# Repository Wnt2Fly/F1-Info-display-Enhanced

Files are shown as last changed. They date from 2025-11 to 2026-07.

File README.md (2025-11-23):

# F1 Tracker - 3 Color E-Paper Display with Enhanced Features

This is an enhanced version of https://github.com/mazur888/F1-Info-display. Including new features, caching and adjustable updates. Designed specifically for a ESP32-C3 Supermini and a 3-color e-paper display. Shows race calendar, driver standings, constructor standings, starting grids, and race results with intelligent update scheduling based on race timing.

<p align="center">
<a href="https://www.buymeacoffee.com/wnt2fly" target="_blank">Buy Me A Coffee</a>
</p>

  

## Features

- 📅 **Race Calendar** - Shows next and last race information
- 🏁 **Starting Grid** - Displays qualifying positions when available (within 18h of race)
- 🏆 **Driver Standings** - Top 10 drivers with points
- 🏎️ **Constructor Standings** - Top 5 constructors with points
- 🥇 **Race Results** - Podium finishers from last race
- ⏱️ **Countdown Timer** - Time until next race with local timezone support
- 🔄 **Smart Updates** - Update frequency adapts based on proximity to race events
- 💾 **Intelligent Caching** - Reduces API calls with multi-level caching
- 🌐 **WiFi Manager** - Easy WiFi setup via captive portal

## Hardware Requirements

### Required Components
- **ESP32-C3 Mini** (or compatible ESP32-C3 board)
- **3-Color E-Paper Display** - GxEPD2_290_C90c (296x128 pixels)
- **SPI Connections** - For display communication
- **Power Supply** - 3.3V/5V depending on your setup

### Pin Connections

| Display Pin | ESP32-C3 Pin | Function |
|---|---|---|
| BUSY | GPIO 4 | Busy signal |
| RST | GPIO 5 | Reset |
| DC | GPIO 7 | Data/Command |
| CS | GPIO 3 | Chip Select |
| SCK | GPIO 6 | SPI Clock |
| MOSI | GPIO 10 | SPI Data |

## Installation

### 1. Arduino IDE Setup

1. Install **Arduino IDE** (1.8.x or 2.x)
2. Add ESP32 board support:
   - File → Preferences → Additional Boards Manager URLs
   - Add: `https://raw.githubusercontent.com/espressif/arduino-esp32/gh-pages/package_esp32_index.json`
   - Tools → Board → Boards Manager → Search "ESP32" → Install

### 2. Install Required Libraries

Install the following libraries via Library Manager (Sketch → Include Library → Manage Libraries):

- **ArduinoJson** (v7.x) - JSON parsing
- **GxEPD2** - E-paper display driver
- **U8g2_for_Adafruit_GFX** - Font rendering
- **WiFiManager** - WiFi configuration
- **Preferences** - Built-in ESP32 library

### 3. Board Configuration

**Tools → Board:** Select your ESP32-C3 board (e.g., "ESP32C3 Dev Module")

**Tools → Partition Scheme:** Select **"Huge APP (3MB No OTA)"** or **"No OTA (3MB)"**
- This gives you 3MB for your application (vs 1.4MB with OTA partition)

**Other Settings:**
- **Flash Size:** 4MB (if available)
- **CPU Frequency:** 160MHz (or 80MHz for lower power)
- **Upload Speed:** 921600 (or lower if you have issues)

### 4. Upload Code

1. Open `F1_Tracker_3Color.ino` in Arduino IDE
2. Connect ESP32-C3 via USB
3. Select correct COM port (Tools → Port)
4. Click Upload

## First Time Setup

### WiFi Configuration

On first boot, the device will create a WiFi access point:

1. **SSID:** `F1Tracker-Setup`
2. **Password:** `formula1`
3. Connect to this network from your phone/computer
4. A captive portal should open automatically (or navigate to `192.168.4.1`)
5. Select your home WiFi network and enter password
6. The device will save credentials and connect

The display will show setup instructions during this process.

### Display Modes

The display automatically switches between 4 modes based on race timing:

**Mode 1: Normal Operation** (>18 hours before race):
- Shows driver standings (top 10)
- Shows constructor standings (top 5)
- Shows last race podium (if results available)
- Shows next race countdown

**Mode 2: Race Approaching** (within 18h before race, grid available):
- Switches to starting grid (qualifying positions)
- Shows constructor standings (top 5)
- Hides old podium, shows "Awaiting Results"
- Shows next race info with "Awaiting Results" message

**Mode 3: Race In Progress** (race started, results not available yet):
- Shows "Current Race: [Name]"
- Shows "Race in Progress!"
- Shows starting grid (continues during race)
- Shows empty podium (no names, just boxes)

**Mode 4: Post-Race** (results available):
- Shows driver standings (switched from grid)
- Shows constructor standings (top 5)
- Shows last race podium with winner names
- Shows next race information

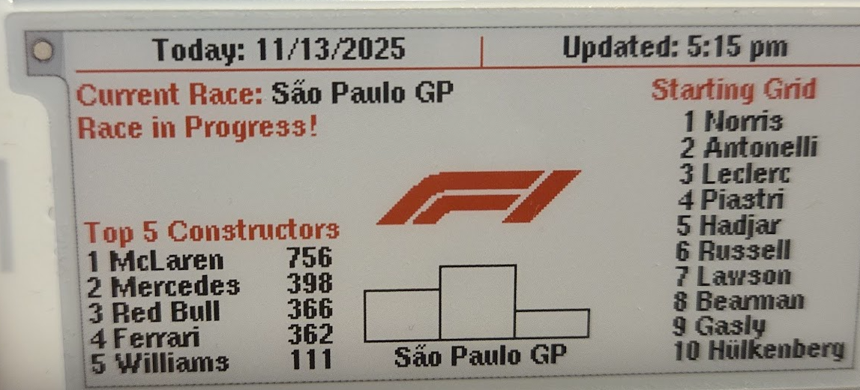
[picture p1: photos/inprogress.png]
Race in Progress Screen


## Update Schedule

The display automatically adjusts update frequency based on race timing:

| Time Before Race | Update Frequency | Reason |
|---|---|---|
| **>48 hours** | Every 6 hours | Nothing changes, minimal updates |
| **24-48 hours** | Every 2 hours | Grid might be posted |
| **<24 hours** | Every 30 minutes | Actively searching for starting grid |
| **Grid Found** | Every 2 hours | Grid found, back to normal until race |
| **Race Window** (6h before to 6h after) | Every 30 minutes | Frequent updates during race event |
| **After Race** | Every 2 hours | Normal operation |

**Update Times:**
- 6-hour updates: 12:00 AM, 6:00 AM, 12:00 PM, 6:00 PM
- 2-hour updates: Even hours at :00 (12:00 AM, 2:00 AM, 4:00 AM, etc.)
- 30-minute updates: :00 and :30 of every hour

## API Information

### Data Source
- **API:** Ergast F1 API (via jolpi.ca proxy)
- **Base URL:** `https://api.jolpi.ca/ergast/f1/{year}/`
- **Endpoints Used:**
  - `/races.json` - Race calendar
  - `/driverstandings.json` - Driver championship
  - `/constructorstandings.json` - Constructor championship
  - `/{round}/qualifying.json` - Starting grid
  - `/{round}/results.json` - Race results

### Caching Strategy

The code uses intelligent multi-level caching:

- **Calendar Cache:** 1 hour TTL
- **Standings Cache:** 1 hour TTL (invalidated when race finishes)
- **Qualifying Cache:** 24 hours TTL (never changes once posted)
- **Results Cache:** 1 hour TTL
- **Availability Cache:** 
  - Qualifying: 12 hours (never changes once posted)
  - Results: 5 minutes (can appear after race)

This reduces API calls by ~99% compared to no caching.

## Configuration

### Timezone

Default timezone is set to **EST/EDT** (Eastern Time). To change:

Edit line 147 in `F1_Tracker_3Color.ino`:
```cpp
#define MY_TZ "EST5EDT,M3.2.0/2,M11.1.0/2"
```

For other timezones, use TZ format:
- PST: `"PST8PDT,M3.2.0/2,M11.1.0/2"`
- GMT: `"GMT0"`
- See [TZ database](https://en.wikipedia.org/wiki/List_of_tz_database_time_zones) for full list

### Update Intervals

Update frequencies can be adjusted in the code (lines 32-35):

```cpp
const int UPDATE_INTERVAL_FAR_MIN = 360;        // >48h: 6 hours
const int UPDATE_INTERVAL_NORMAL_MIN = 120;     // Normal: 2 hours
const int UPDATE_INTERVAL_RACE_WINDOW_MIN = 30; // Race window: 30 min
const int UPDATE_INTERVAL_GRID_SEARCH_MIN = 30; // Grid search: 30 min
```

### Debug Mode

Debug mode allows you to test all display modes without waiting for actual race events. It simulates different times relative to a past race, allowing you to cycle through all scenarios interactively.

#### Enabling Debug Mode

1. Open `F1-Info-display-Enhanced.ino` in Arduino IDE
2. Find line 42: `#define DEBUG_MODE 0`
3. Change to: `#define DEBUG_MODE 1`
4. Upload the code

#### Using Debug Mode

1. **Open Serial Monitor** (115200 baud)
2. **Wait for initial setup** - Let the device connect to WiFi and fetch calendar data
3. **Use interactive commands** to test different scenarios

#### Interactive Menu

When debug mode starts, an interactive menu is displayed. You can use either **numbers (1-8)** or **full commands**:

**Menu Options:**
- `1` or `normal` - Jump to 3 days before race (Mode 1: Normal Operation)
- `2` or `before` - Jump to 2 hours before race (Mode 2: Race Approaching)
- `3` or `during` - Jump to race start time (Mode 3: Race In Progress)
- `4` or `after` - Jump to 5 hours after race start (Mode 4: Post-Race)
- `5` or `refresh` - Force immediate display update
- `6` or `status` - Show current offset, real time, simulated time, and race state
- `7` or `reset` - Reset to default offset (-30 days)
- `8` or `autorefresh` - Toggle auto-refresh on/off (default: OFF in debug mode)

**Time Adjustments** (also available):
- `+1h`, `+2h`, `+6h` - Add hours to time offset
- `-1h`, `-2h`, `-6h` - Subtract hours from time offset
- `+1d`, `+2d`, `+7d` - Add days to time offset
- `-1d`, `-2d`, `-7d` - Subtract days from time offset
- `set <seconds>` - Set exact time offset (e.g., `set -2592000`)

**Menu Commands:**
- `menu` or `help` or `?` - Show menu again

#### Example Workflow

```
1. Upload code with DEBUG_MODE = 1
2. Open Serial Monitor (115200 baud)
3. Wait for calendar fetch
4. Type "status" - see current state
5. Type "normal" - see Mode 1 (driver standings, countdown)
6. Type "before" - see Mode 2 (starting grid, awaiting results)
7. Type "during" - see Mode 3 (race in progress, empty podium)
8. Type "after" - see Mode 4 (post-race, results if available)
```

#### Important Notes

- **Commands are case-insensitive** (e.g., `STATUS` = `status`)
- **Serial Monitor settings:** 115200 baud, "Newline" or "Both NL & CR" line ending
- **Display refresh takes 15-30 seconds** - this is normal for e-paper displays
- **Menu reappears after commands** - After each mode command (1-4) or refresh (5) completes, the menu is shown again
- **Auto-refresh disabled by default** - Display only updates when you select a menu option (1-5)
- **WiFi stays connected** - In debug mode, WiFi remains connected for faster testing
- **Jump commands auto-refresh** - Options 1-4 automatically update the display after jumping to that time
- **Time adjustments don't refresh** - Use `+1h`, `-2h`, etc. then type `5` or `refresh` to update display
- **API calls use real time** - Debug mode only affects time calculations, not API data

#### Debug Mode Display Indicator

When debug mode is enabled, the display shows `[DEBUG] Mode X` in the header (where X is 1-4) instead of `Today:` to indicate you're in test mode and show the current display mode.

## Power Consumption

- **During Update:** ~50-100mA (display refresh takes ~15-30 seconds)
- **Hibernating:** ~10-20µA (display in deep sleep)
- **Average:** Very low due to hibernation between updates
- **Battery Life:** Weeks to months depending on update frequency and battery capacity

## Troubleshooting

### Display Not Updating

1. **Check WiFi Connection**
   - Serial monitor will show connection status
   - Device restarts if WiFi disconnects

2. **Check Time Sync**
   - Device needs NTP time sync to work
   - Serial monitor shows time sync status
   - Ensure internet connection is working

3. **Check API Access**
   - Serial monitor shows API call status
   - Verify API endpoint is accessible

### Display Shows Garbage/Corruption

1. **Power Supply**
   - Ensure stable 3.3V/5V power
   - Display needs adequate current during refresh

2. **SPI Connections**
   - Verify all pins connected correctly
   - Check for loose connections

3. **Full Refresh**
   - Display uses full refresh (not partial)
   - This is normal for 3-color displays

### WiFi Setup Issues

1. **Can't Connect to Setup AP**
   - SSID: `F1Tracker-Setup`
   - Password: `formula1`
   - Some devices may not auto-open portal - navigate to `192.168.4.1`

2. **WiFi Credentials Not Saving**
   - Check Preferences library is working
   - Device should remember credentials after first setup

### Compilation Errors

1. **"Board not found"**
   - Install ESP32 board support (see Installation)

2. **"Library not found"**
   - Install required libraries (see Installation)

3. **"Partition too small"**
   - Select "Huge APP (3MB No OTA)" partition scheme

## Technical Details

### Memory Usage

- **Flash:** ~450KB (code + libraries)
- **RAM:** ~40-70KB (with 400KB available on ESP32-C3)
- **JSON Buffer:** 12KB (optimized from 16KB)

### Display Specifications

- **Model:** GxEPD2_290_C90c
- **Resolution:** 296x128 pixels
- **Colors:** Black, White, Red (3-color)
- **Refresh Time:** ~15-30 seconds (full refresh)
- **Rotation:** 270° (landscape mode)

### Code Structure

- **Main Loop:** Checks time every 60 seconds, triggers updates on schedule
- **Update Function:** Fetches data, draws to display, hibernates
- **Caching:** Multi-level cache reduces API calls
- **Error Handling:** Graceful degradation on API failures
- **Debug Mode:** Interactive time simulation for testing all display modes

## License

This project is open source. Feel free to modify and use as needed.

## Credits

- **F1 Data:** Ergast F1 API (via jolpi.ca)
- **Display Library:** GxEPD2 by ZinggJM
- **Font Rendering:** U8g2
- **WiFi Management:** WiFiManager by tzapu

## Support

For issues or questions:
1. Check Serial Monitor output for debug information
2. Verify all connections and power supply
3. Ensure WiFi and internet connectivity
4. Check API endpoint accessibility

---

**Enjoy your F1 Tracker! 🏎️🏁**

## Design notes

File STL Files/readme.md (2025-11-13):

##  Like this project? [Buy me a coffee](coff.ee/mazur888)  

## Printer:  
I used Creality K1C  
hyper pla, no supports default speed and layer settings in creality print.  

## What else is needed:  
#1 One or two small screws to attach front frame to base (there are 2 pilot holes).  
#2 One USB C connector like this (2 or 4 wire):  
#3 Optional: 2x 5k1 resistors.  

## Electronics:  
#1  If you dont care about USB C to C you can use **2 wire connector** and solder positive to esp32 dev board's 5V and GND to GND,  
this will give you standard USB A to USB C option only, C to C wont work.

#2 If you want to use C- C cable, you have to buy **4 wire connector**. Solder positive to esp32 dev board's 5V, GND to GND,  
and solder resistors between CC1 and GND, and CC2 and GND to enable power when used C to C cables. 

## Assembly:  
#1 place screen in to front frame and using soldering iron melt corner pins to hold screen in place,  
#2 fish usb connector cable from bottom compartment through back plate into screen and solder wires,  
#3 close back cover and place front in base,  
4# secure front using small screw through bottom compartment,  
5# use bottom compartment to hide excess cable and close it using bottom cap.    

## Connector type used:  
Screenshot From 2025-07-17 09-56-34

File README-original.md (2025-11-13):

# Formula 1 Info tracker  
  
main1 

## Pole Position before race:  

pole

## Dashboard     
  
Dash 1
   
## About this project  
Formula 1 info screen, is based on esp32 and **2.9"  3 color E-Paper module from weact studio** and ergast API, It allows to track Formula 1 events, dates, points, stats and many more on e-paper display and weserver dashboard.  
  
**Features:**  
  
- mDNS option (**f1tracker.local**), or device IP address for dashboard or OTA  
- Data is fetched from **ergast** API and displayed on the screen every 30 minutes,  
- OTA Uploads  
- Full online dashboard including season calendar, all season rounds, pole positions, driver points etc..  
- Automatic winter/summer time change  
- wifi AP mode for fast wifi setup  
    
**Default data on E-paper:**  
  
- Top 5 Teams including constructors points for current season   
- Top 10 drivers including season points   
- Last race location including podium places   
- Next race location and date  
- Pole position for next race  
  
<p align="center">
<a href="https://www.buymeacoffee.com/mazur888" target="_blank">Buy Me A Coffee</a>
</p>
  
## **Hardware:**  
E-Paper module: [2.9 Inch 3-color weact studio e-paper module](https://www.aliexpress.com/item/1005005183232092.html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)  
ESP32: [Esp32 dev board](https://www.aliexpress.com/item/1005005476182210.html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)
  
**ESP32 to Screeen Connections:**  
BUSY = 4  
CS = 5  
RST = 16  
DC = 17  
SCK = 18  
MISO = 19  
MOSI = 23  
  
## **Software:**
**WiFI access point login details:**  
- SSID "F1 display"  
- PASS "formula1"  
  
**Time zones:**  
- Change time zone to match your location. default time zone is BST for United Kingdom  
  
MET-1METDST,M3.5.0/01,M10.5.0/02   //Europe  
CET-1CEST,M3.5.0,M10.5.0/3         // Central Europe  
EST-2METDST,M3.5.0/01,M10.5.0/02   // Europe  
EST5EDT,M3.2.0,M11.1.0           // EST USA  
CST6CDT,M3.2.0,M11.1.0           // CST USA  
MST7MDT,M4.1.0,M10.5.0           // MST USA  
NZST-12NZDT,M9.5.0,M4.1.0/3      // Auckland  
EET-2EEST,M3.5.5/0,M10.5.5/0     // Asia  
ACST-9:30ACDT,M10.1.0,M4.1.0/3   // Australia  
  
**API Updates:**  
- Screen and dashboard updates are pulled from server every 30 minutes
  
**Software Updates:**  
- If you wish to update the software, OTA server is available under devices IP or f1tracker.local
  
## **Third‑Party Libraries**  
- **GxEPD2** (v1.6.4) by ZinggJM — GPL 3.0  
- **U8g2_for_Adafruit_GFX** (v1.8.0) by olikraus — BSD 2‑Clause  
- **WiFiManager** (v2.0.17) by tzapu — MIT  
- **ArduinoJson** (v7.4.2) by Benoit Blanchon — MIT

## Enclosure
- STL Files are included in this project  
  
**Printer:**  
Any printer will be ok, For this project I used Creality K1C and hyper pla  
all settings default in creality print  
printed with no supports  
  
## License
This project is released under the [GNU GPL v3.0](LICENSE).  
© 2025 Mazur888. No warranty; use at your own risk.

<p align="center">
<a href="https://www.buymeacoffee.com/mazur888" target="_blank">Buy Me A Coffee</a>
</p>

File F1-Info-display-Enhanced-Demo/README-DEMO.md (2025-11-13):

# F1 Tracker - Demo Mode

A demonstration version of the F1 Tracker that automatically cycles through all display modes. This is designed for **taking photos** of the device in different states and is **NOT intended for production use**.

## ⚠️ Important Notice

**This is a TEMPORARY demo file to verify your setup is working**

- **DO NOT** use this in production
- **DO NOT** leave this running permanently
- Use `F1-Info-display-Enhanced.ino` for normal operation

## Purpose

This demo file automatically cycles through all 4 display modes every 7 seconds, making it easy to photograph the device showing:
- Normal operation mode
- Race approaching mode
- Race in progress mode
- Post-race mode

## Features

### Automatic Mode Cycling
- **4 Display Modes** that cycle automatically
- **7-second intervals** between mode changes (configurable)
- **Real API data** from Ergast F1 API
- **Continuous loop** until power off or code change

### Display Modes

#### Mode 0: Normal Operation
- **Top 10 Drivers** standings with points
- **Top 5 Constructors** standings
- **Last Race Podium** with winner names
- **Next Race** information with countdown

#### Mode 1: Race Approaching (Within 18h)
- **Starting Grid** (qualifying positions)
- **Top 5 Constructors** standings
- **"Awaiting Results"** podium placeholder
- **Next Race** information

#### Mode 2: Race In Progress
- **"Race in Progress!"** indicator
- **Starting Grid** (current race)
- **Top 5 Constructors** standings
- **Empty Podium** (no results yet)

#### Mode 3: Post-Race
- **Top 10 Drivers** standings with points
- **Top 5 Constructors** standings
- **Last Race Podium** with winner names
- **Next Race** information

## Hardware Requirements

Same as the main F1 Tracker:
- **ESP32-C3 Mini** (or compatible ESP32-C3 board)
- **3-Color E-Paper Display** - GxEPD2_290_C90c (296x128 pixels)
- **SPI Connections** - See pin mapping below

### Pin Connections

| Display Pin | ESP32-C3 Pin | Function |
|---|---|---|
| BUSY | GPIO 4 | Busy signal |
| RST | GPIO 5 | Reset |
| DC | GPIO 7 | Data/Command |
| CS | GPIO 3 | Chip Select |
| SCK | GPIO 6 | SPI Clock |
| MOSI | GPIO 10 | SPI Data |

## Installation

### 1. Prerequisites

Same requirements as the main project:
- **Arduino IDE** (1.8.x or 2.x)
- **ESP32 board support** installed
- **Required libraries:**
  - ArduinoJson (v7.x)
  - GxEPD2
  - U8g2_for_Adafruit_GFX
  - WiFiManager

### 2. Upload Demo Code

1. Open `F1-Info-display-Enhanced-Demo.ino` in Arduino IDE
2. Select your ESP32-C3 board
3. Select partition scheme: **"Huge APP (3MB No OTA)"**
4. Connect ESP32-C3 via USB
5. Select correct COM port
6. Click **Upload**

### 3. First Run

On first boot:
1. Device creates WiFi AP: `F1Tracker-Setup` (password: `formula1`)
2. Connect to this network from your phone/computer
3. Select your home WiFi network in the captive portal
4. Device connects and fetches F1 data
5. Demo mode starts automatically

## Usage

### Starting the Demo

1. **Upload the code** to your ESP32-C3
2. **Wait for WiFi connection** (first time setup may be needed)
3. **Data loads** - you'll see "DEMO MODE - Cycling through all modes..."
4. **Demo starts** - modes cycle automatically every 7 seconds

### Taking Photos

1. **Position your camera** ready to photograph the display
2. **Wait for the mode** you want to capture
3. **Take the photo** - you have 7 seconds per mode
4. **Wait for next mode** or restart if needed

### Mode Timing

- Each mode displays for **7 seconds**
- Full cycle (4 modes) takes **28 seconds**
- Modes cycle in order: 0 → 1 → 2 → 3 → 0 (repeat)

### Stopping the Demo

- **Power off** the device, or
- **Upload different code** (e.g., the main F1 Tracker code)

## Configuration

### Changing Display Interval

To change how long each mode displays, edit line 26 in the demo file:

```cpp
const int DEMO_DELAY_MS = 7000;  // Change this value (in milliseconds)
```

Examples:
- `5000` = 5 seconds per mode
- `10000` = 10 seconds per mode
- `15000` = 15 seconds per mode

### Changing Starting Mode

To start from a different mode, edit line 25:

```cpp
int demoMode = 0;  // 0=Normal, 1=Race Approaching, 2=Race In Progress, 3=Post-Race
```

## Serial Monitor Output

The demo provides detailed serial output:

```
=== F1 TRACKER DEMO MODE ===
Cycles through all display modes every 7 seconds

[WiFi] Starting WiFi setup...
[WiFi] Connected!
IP: 192.168.1.xxx

[Time] Synced!

[DEMO] Fetching calendar data...
[DATA] Last: R23 Abu Dhabi GP
[DATA] Next: R1 Bahrain GP

[DEMO] Data loaded. Starting mode cycle...

[DEMO] Switching to mode 0
[DEMO] Mode 0: Normal
[DEMO] Switching to mode 1
[DEMO] Mode 1: Race Approaching
[DEMO] Switching to mode 2
[DEMO] Mode 2: Race In Progress
[DEMO] Switching to mode 3
[DEMO] Mode 3: Post-Race
```

## Troubleshooting

### Display Not Updating

1. **Check Serial Monitor** - Look for error messages
2. **Verify WiFi Connection** - Device must be connected to internet
3. **Check API Access** - Verify API endpoint is accessible
4. **Wait for Data Load** - First data fetch may take 10-30 seconds

### Wrong Data Showing

- **API may not have data** for current/next race
- Demo uses **last completed race** for podium results
- Demo uses **next race** for starting grid (if available)
- If no qualifying data exists, grid will show "No grid data"

### Mode Not Changing

- **Check Serial Monitor** - Should show mode changes every 7 seconds
- **Verify code uploaded correctly** - Re-upload if needed
- **Check display refresh** - E-paper takes 15-30 seconds to refresh

### WiFi Issues

- **First time:** Connect to `F1Tracker-Setup` AP and configure
- **Subsequent runs:** Device remembers WiFi credentials
- **Reset WiFi:** Hold reset button or erase flash if needed

## Data Requirements

The demo needs internet access to fetch:
- **Race Calendar** - Last and next race information
- **Driver Standings** - Current championship standings
- **Constructor Standings** - Team championship standings
- **Qualifying Results** - Starting grid positions
- **Race Results** - Podium finishers

If any data is unavailable:
- Demo will still run but may show placeholder text
- Some modes may look incomplete
- Check Serial Monitor for specific errors

## Returning to Normal Operation

To switch back to the main F1 Tracker:

1. **Open** `F1-Info-display-Enhanced.ino` in Arduino IDE
2. **Upload** to your ESP32-C3
3. Device will resume normal operation with intelligent scheduling

## Technical Details

### Memory Usage
- Similar to main code: ~450KB flash, ~40-70KB RAM
- No caching in demo mode (fetches fresh data each cycle)
- More API calls than production code

### Power Consumption
- **Higher than production** - WiFi stays connected, display refreshes every 7 seconds
- **Not optimized** for battery operation
- **Intended for** short photography sessions

### API Calls
- Makes API calls for each mode change
- No caching (unlike production code)
- May hit rate limits if run for extended periods

## Limitations

- **Not optimized** for power consumption
- **No intelligent scheduling** - just cycles modes
- **No caching** - fetches data every cycle
- **Continuous operation** - doesn't hibernate
- **WiFi always on** - unlike production code

## Support

For issues:
1. Check **Serial Monitor** output for error messages
2. Verify **WiFi connection** is stable
3. Ensure **API endpoint** is accessible
4. Check **pin connections** are correct

## License

Same license as the main project. See `LICENSE` file for details.

---

**Remember:** This is a **DEMO ONLY** file. Use `F1-Info-display-Enhanced.ino` for normal operation! 🏎️

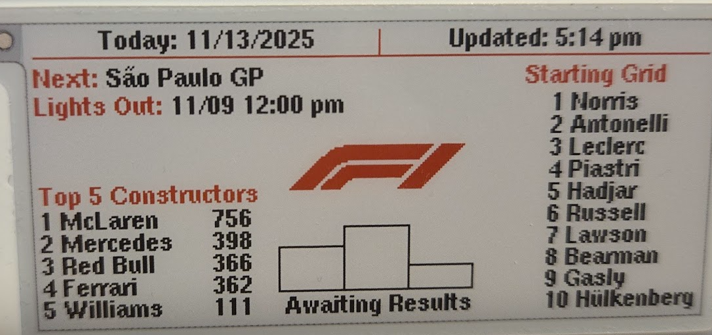
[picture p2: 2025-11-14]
STL Files/startinggrid.png

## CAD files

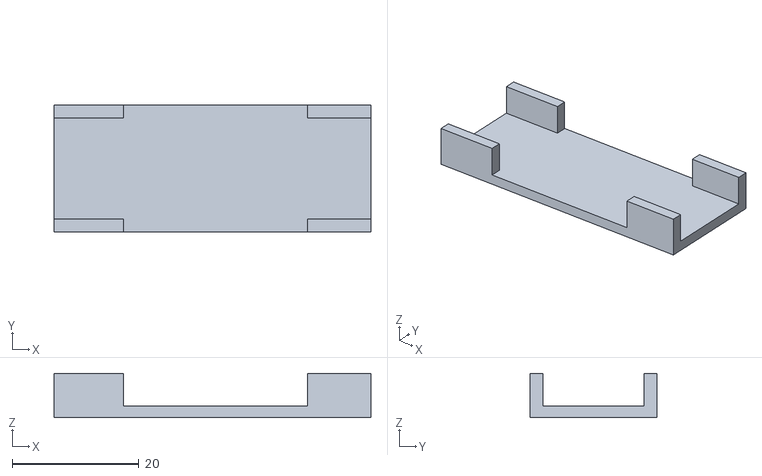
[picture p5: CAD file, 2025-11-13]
STL Files/2.9 v2 base cap.stl
50.0 x 20.0 x 7.00

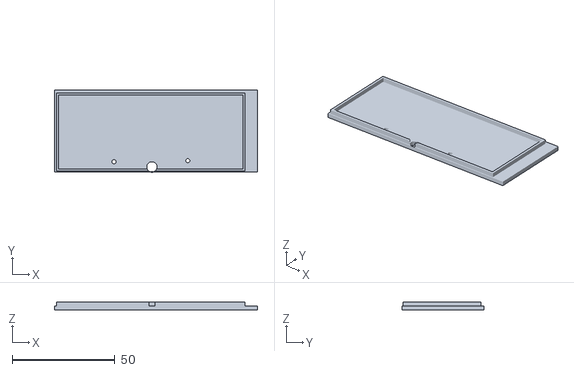
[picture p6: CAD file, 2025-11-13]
STL Files/2.9 v2 back plate.stl
99.0 x 40.0 x 4.00

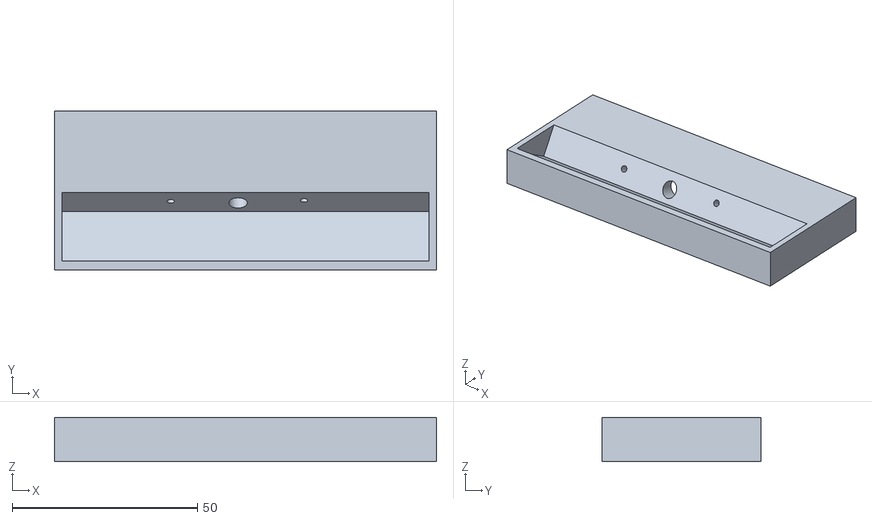
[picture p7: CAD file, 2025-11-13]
STL Files/2.9 v2 base.stl
103.2 x 43.0 x 12.0

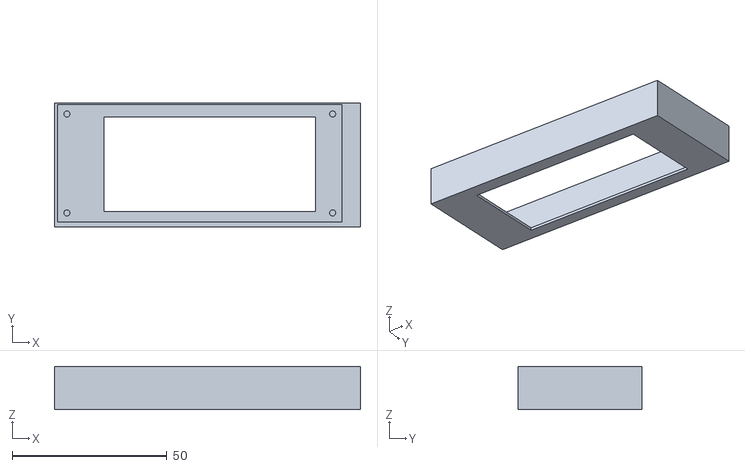
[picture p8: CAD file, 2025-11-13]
STL Files/2.9 v2 front.stl
99.0 x 40.0 x 14.0

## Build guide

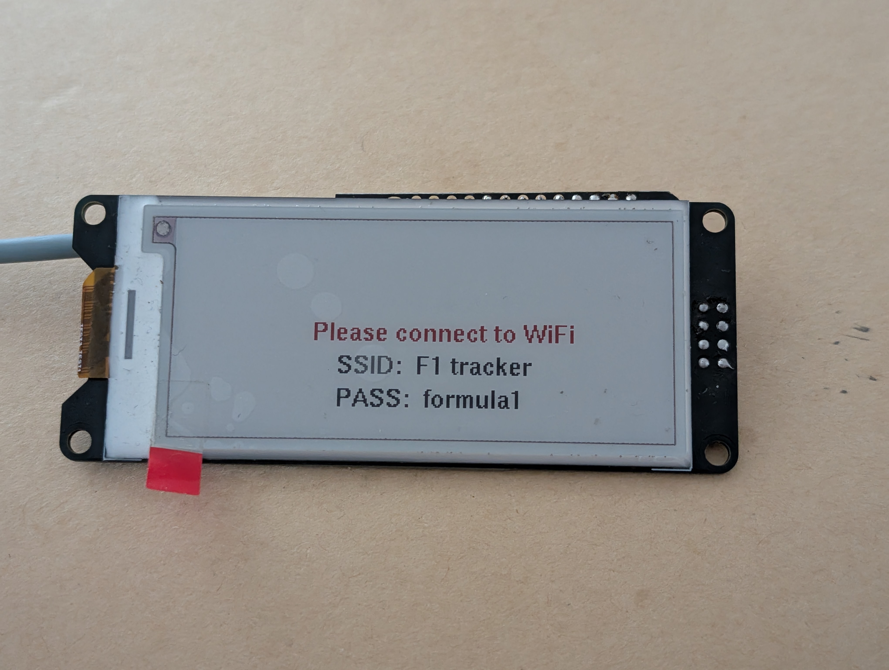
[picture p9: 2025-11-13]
photos/wifi setup screen.jpg

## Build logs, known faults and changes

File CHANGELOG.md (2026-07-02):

# Changelog

All notable changes to the F1 Info Display Enhanced project will be documented in this file.

## [Unreleased]

### Fixed
- **HTTP JSON parsing reliability** - Buffer full API response before parsing instead of streaming directly from the TLS socket, fixing `IncompleteInput` errors on larger endpoints (race calendar, driver standings) over HTTPS

## [1.1.0] - 2024-12-XX

### Added

#### Debug Mode
- **Interactive Debug Mode** - Complete time simulation system for testing all display modes
  - Set `DEBUG_MODE` to 1 to enable interactive testing
  - Time offset simulation allows testing scenarios using past races
  - All time calculations use simulated time while API calls use real time
  - Display shows `[DEBUG] Mode X` indicator in header when in debug mode
  - WiFi stays connected in debug mode for faster testing
  - Auto-refresh disabled by default in debug mode (only updates on manual command)

#### Interactive Debug Menu
- **Numbered Menu System** - Easy-to-use menu with numbered options (1-8)
  - Menu automatically displays on startup
  - Menu reappears after each command completes
  - Type numbers (1-8) or full commands - both work
- **Menu Options:**
  - `1` or `normal` - Jump to 3 days before race (Mode 1: Normal Operation)
  - `2` or `before` - Jump to 2 hours before race (Mode 2: Race Approaching)
  - `3` or `during` - Jump to race start time (Mode 3: Race In Progress)
  - `4` or `after` - Jump to 5 hours after race start (Mode 4: Post-Race)
  - `5` or `refresh` - Force immediate display update
  - `6` or `status` - Show current offset, real time, simulated time, and race state
  - `7` or `reset` - Reset to default offset (-30 days)
  - `8` or `autorefresh` - Toggle auto-refresh on/off
- **Time Adjustments** (also available):
  - `+1h`, `+2h`, `+6h` - Add hours to time offset
  - `-1h`, `-2h`, `-6h` - Subtract hours from time offset
  - `+1d`, `+2d`, `+7d` - Add days to time offset
  - `-1d`, `-2d`, `-7d` - Subtract days from time offset
  - `set <seconds>` - Set exact time offset
- **Menu Commands:**
  - `menu` or `help` or `?` - Show menu again

#### Display Mode Improvements
- **Mode 1: Normal Operation** - Driver standings, countdown, last race podium
- **Mode 2: Race Approaching** - Starting grid, "Awaiting Results" message
- **Mode 3: Race In Progress** - "Race in Progress!" indicator, starting grid, empty podium
- **Mode 4: Post-Race** - Driver standings (when results available), podium with winners

### Fixed

#### Scheduler Improvements
- **Race State Detection** - Fixed scheduler to continue updates during and after race
  - Added `lastRaceJustFinished` check that runs before checking `nextRaceEpoch`
  - Ensures 30-minute updates continue for 4 hours after race start
  - Handles case where race moves from "next" to "last" in API
  - Prevents display from getting stuck at last update time

#### Display Logic Fixes
- **Grid vs Standings Display** - Fixed logic for when to show starting grid vs driver standings
  - Grid shows: Before race (within 18h) OR during race until results available
  - Driver standings show: After results become available
  - Grid never shows after results are posted
- **"Awaiting Results" Display** - Fixed to show "Awaiting Results" instead of countdown when grid is displayed
  - Shows "Awaiting Results" in Next Race section when starting grid is active
  - Properly indicates race is approaching and results are pending
- **Mode 2 Podium Display** - Fixed to show blank podium with "Awaiting Results" instead of old race results
  - Mode 2 (Race Approaching) now correctly hides previous race podium
  - Shows empty podium boxes with "Awaiting Results" text
- **Mode 3 Grid Display** - Fixed to always show starting grid during race
  - Mode 3 (Race In Progress) now correctly displays grid regardless of qualifying data availability
  - Handles race moving from nextRound to lastRound in API
- **Mode 4 Detection** - Fixed "after" command to jump to 5 hours after race start
  - Ensures Mode 4 is correctly detected (requires >4h past race and not in race window)
  - Properly shows driver standings and podium with results

#### Serial Communication
- **Enhanced Serial Output** - Added progress messages for debug commands
  - Shows step-by-step progress during display refresh
  - Indicates when WiFi is connecting, calendar is fetching, and display is refreshing
  - Provides feedback that 15-30 second refresh time is normal for e-paper displays
- **Interactive Menu System** - Menu displays automatically and after each command
  - Shows numbered options for easy selection
  - Displays current auto-refresh status
  - Menu reappears after commands complete for continuous testing

### Changed

#### Time Management
- **Simulated Time System** - New `getSimulatedTime()` and `getSimulatedLocalTime()` functions
  - All race state detection uses simulated time in debug mode
  - API calls continue to use real time for correct data fetching
  - Time offset is configurable via `debugTimeOffsetSeconds` variable

#### Code Organization
- **Debug Mode Compilation** - All debug features compile out when `DEBUG_MODE = 0`
  - No performance impact in production mode
  - Clean separation between debug and production code
- **Code Simplification** - Removed redundant mode detection calls from display functions
  - DrawDrivers() and DrawLastRace() use simple timing checks
  - Mode detection only used in DrawTime() for header display
  - Reduced code complexity while maintaining functionality

### Technical Details

#### New Functions
- `getSimulatedTime()` - Returns real time + offset in debug mode
- `getSimulatedLocalTime()` - Populates timeinfo with simulated time
- `getCurrentDisplayMode()` - Returns current display mode (1-4) in debug mode
- `handleDebugCommands()` - Processes interactive serial commands
- `printDebugMenu()` - Displays interactive menu with numbered options

#### Modified Functions
- `DrawDrivers()` - Simplified logic using timing checks (grid before/during race, standings otherwise)
- `DrawLastRace()` - Fixed to show blank podium in Mode 2, results in Mode 4
- `DrawNextRace()` - Added check for grid display to show "Awaiting Results"
- `DrawTime()` - Shows `[DEBUG] Mode X` in header when debug mode enabled
- `shouldUpdateNow()` - Added `lastRaceJustFinished` check for post-race updates
- `disconnectWiFiIfIdle()` - Keeps WiFi connected in debug mode for faster testing
- `loop()` - Checks for debug commands every second (instead of 60s) for responsive interaction
- `setup()` - Added debug mode initialization and menu display

#### Constants and Variables
- `DEBUG_MODE` - Compile-time flag to enable/disable debug mode
- `debugTimeOffsetSeconds` - Runtime variable for time offset (default: -30 days)
- `debugAutoRefresh` - Runtime flag to enable/disable auto-refresh in debug mode (default: false)

## [1.0.0] - Initial Release

### Added
- Race calendar display
- Driver standings (top 10)
- Constructor standings (top 5)
- Starting grid display (when available)
- Race results podium
- Smart update scheduling based on race timing
- Multi-level caching system
- WiFi Manager for easy setup
- Timezone support (EST/EDT default)

---

**Note:** This changelog follows [Keep a Changelog](https://keepachangelog.com/en/1.0.0/) format.

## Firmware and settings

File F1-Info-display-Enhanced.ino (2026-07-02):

// Mac 64:E8:33:B8:F6:28

#include <WiFi.h>
#include <HTTPClient.h>
#include <ArduinoJson.h> // v7
#include <time.h>
#include <SPI.h>
#define ENABLE_GxEPD2_display 0
#include <GxEPD2_3C.h>
#include <U8g2_for_Adafruit_GFX.h>
#include <WiFiManager.h>
#include <Preferences.h>
#include <ctype.h>

// ------------------- WIFI/NETWORK ----------------------
enum screenAlignment { LEFT, RIGHT, CENTER };
bool wifiConnected = false;

// Scheduler Variables - NOW USING WALL CLOCK ALIGNMENT
unsigned long lastCheckMinute = 0;  // Track which minute we last checked

// ------------------- DEBUG MODE ----------------------
// Set to 1 to enable debug mode with time offset simulation
// In debug mode, all time calculations use simulated time, but API calls use real time
// This allows testing race scenarios using past races that have complete data
//
// INTERACTIVE COMMANDS (when DEBUG_MODE = 1):
// Open Serial Monitor (115200 baud) and send commands:
//   +1h, +2h, +6h    - Add hours to offset
//   -1h, -2h, -6h    - Subtract hours from offset
//   +1d, +2d, +7d    - Add days to offset
//   -1d, -2d, -7d    - Subtract days from offset
//   set <seconds>    - Set exact offset (e.g., "set -2592000")
//   reset            - Reset to default offset
//   status           - Show current offset and simulated time
//   refresh          - Force immediate display update
//   before           - Jump to 2 hours before race (if race detected)
//   during           - Jump to race start time
//   after            - Jump to 1 hour after race start
//
// IMPORTANT: Set to 1 to enable debug mode, 0 to disable
#define DEBUG_MODE 0

// Time offset in seconds (negative = simulate being in the past relative to real time)
// This is now a variable (not const) so it can be changed interactively in debug mode
// Default: -30 days
long debugTimeOffsetSeconds = -2592000;

// Auto-refresh flag for debug mode (set to false to disable automatic scheduler updates)
// Default to false in debug mode - only refresh when menu option is selected
bool debugAutoRefresh = false;

// ------------------- TIME CONSTANTS ----------------------
// Race timing windows (in seconds)
const long RACE_IN_PROGRESS_WINDOW_SEC = 14400;      // 4 hours - race considered "in progress"
const long RACE_WINDOW_BEFORE_SEC = 21600;           // 6 hours - race window before start
const long RACE_WINDOW_AFTER_SEC = 21600;            // 6 hours - race window after start
const long NEXT_RACE_APPROACHING_SEC = 64800;        // 18 hours - show grid when next race approaching
const long SECONDS_PER_DAY = 86400;                 // 1 day in seconds
const long SECONDS_PER_HOUR = 3600;                 // 1 hour in seconds

// Update frequency constants (in minutes)
const int UPDATE_INTERVAL_FAR_MIN = 360;             // >48h before race: every 6 hours
const int UPDATE_INTERVAL_NORMAL_MIN = 120;          // Normal operation: every 2 hours
const int UPDATE_INTERVAL_RACE_WINDOW_MIN = 30;      // Race window: every 30 minutes
const int UPDATE_INTERVAL_GRID_SEARCH_MIN = 30;      // 24h before race: every 30 min until grid found

// Timing thresholds (in seconds)
const long HOURS_48_BEFORE_RACE_SEC = 172800;       // 48 hours = 2 days
const long HOURS_24_BEFORE_RACE_SEC = 86400;         // 24 hours = 1 day

// ------------------- API ENDPOINTS (PROGMEM) ----------------------
const char API_BASE_TEMPLATE[] PROGMEM = "https://api.jolpi.ca/ergast/f1/%s";
const char API_RACES_SUFFIX[] PROGMEM = "/races.json";
const char API_RESULTS_SUFFIX[] PROGMEM = "/results.json";  
const char API_DRIVER_STAND_SUFFIX[] PROGMEM = "/driverstandings.json";
const char API_CONSTR_STAND_SUFFIX[] PROGMEM = "/constructorstandings.json";

// ------------------- SCREEN / PINS ----------------------
#define SCREEN_WIDTH 296
#define SCREEN_HEIGHT 128
#define listx 225
#define logoWidth 80
#define logoHeight 20

// ------------------- CACHED DRIVER LINES ----------------------
String DRV_LINE[10];
String PTS_LINE[10];
int    DRV_COUNT = 0;

// ---- Layout constants ----
static const int TOP_BAND_H      = 30;
static const int DRIVERS_TITLE_Y = 16;
static const int NEXT_LINE1_Y    = 16;
static const int NEXT_LINE2_Y    = 28;
static const int DRIVERS_ROW_Y0  = 28;
static const int DRIVERS_Y_NUDGE = -4;

// Podium layout constants
static const int PODIUM_LOGO_Y = 50;
static const int PODIUM_1ST_X = 133;
static const int PODIUM_1ST_Y = 86;
static const int PODIUM_1ST_W = 30;
static const int PODIUM_1ST_H = 30;
static const int PODIUM_2ND_X = 104;
static const int PODIUM_2ND_Y = 95;
static const int PODIUM_2ND_W = 30;
static const int PODIUM_2ND_H = 21;
static const int PODIUM_3RD_X = 162;
static const int PODIUM_3RD_Y = 104;
static const int PODIUM_3RD_W = 30;
static const int PODIUM_3RD_H = 12;
static const int PODIUM_TEXT_Y = 118;
static const int PODIUM_TEXT_CENTER_X = 155;
static const int PODIUM_NAME_1ST_Y = 77;
static const int PODIUM_NAME_2ND_X_OFFSET = -38;
static const int PODIUM_NAME_2ND_Y = 86;
static const int PODIUM_NAME_3RD_X_OFFSET = 20;
static const int PODIUM_NAME_3RD_Y = 95;

// --- ESP32 Pin Map ---
static const uint8_t EPDBUSY = 4;
static const uint8_t EPDRST  = 5;
static const uint8_t EPDDC   = 7;
static const uint8_t EPDCS   = 3;
static const uint8_t EPDSCK  = 6;
static const uint8_t EPDMOSI = 10;

GxEPD2_3C<GxEPD2_290_C90c, GxEPD2_290_C90c::HEIGHT> display(
  GxEPD2_290_C90c(EPDCS, EPDDC, EPDRST, EPDBUSY)
);

U8G2_FOR_ADAFRUIT_GFX gfx;

// ------------------- JSON / MEMORY ----------------------
// Optimized: Reduced from 16KB to 12KB (adequate for F1 API responses)
// Saves 4KB RAM with no functionality loss
#define API_SCRATCH_DOC_SIZE 12288
StaticJsonDocument<API_SCRATCH_DOC_SIZE> doc;

// ------------------- API CACHE ----------------------
struct CacheEntry {
  String data;
  unsigned long timestamp;
  bool valid;
};

struct {
  CacheEntry calendar;
  CacheEntry driverStandings;
  CacheEntry constructorStandings;
  CacheEntry qualifying;
  CacheEntry results;  // Race results cache
} apiCache;

// Quick availability cache (per round, lightweight)
struct AvailabilityCache {
  unsigned int round;
  bool qualifyingAvailable;
  bool resultsAvailable;
  unsigned long qualifyingTimestamp;  // Separate timestamp for qualifying
  unsigned long resultsTimestamp;     // Separate timestamp for results
  bool qualifyingValid;
  bool resultsValid;
};
AvailabilityCache availabilityCache = {0, false, false, 0, 0, false, false};
const unsigned long QUALIFYING_AVAILABILITY_TTL = 43200000UL;  // 12 hours - qualifying never changes once posted
const unsigned long RESULTS_AVAILABILITY_TTL = 300000UL;        // 5 minutes - results can appear after race

// Cache TTL (Time To Live) in milliseconds
const unsigned long CACHE_TTL_CALENDAR = 3600000UL;      // 1 hour - calendar rarely changes
const unsigned long CACHE_TTL_STANDINGS = 3600000UL;     // 1 hour - standings only change after races
const unsigned long CACHE_TTL_QUALIFYING = 86400000UL;   // 24 hours - qualifying never changes once posted

void clearCache() {
  apiCache.calendar.valid = false;
  apiCache.driverStandings.valid = false;
  apiCache.constructorStandings.valid = false;
  apiCache.qualifying.valid = false;
  apiCache.results.valid = false;
  availabilityCache.qualifyingValid = false;
  availabilityCache.resultsValid = false;
  Serial.println(F("[Cache] Cleared all cache"));
}

void invalidateStandingsCache() {
  // Call this when race finishes to refresh standings
  apiCache.driverStandings.valid = false;
  apiCache.constructorStandings.valid = false;
  Serial.println(F("[Cache] Invalidated standings cache"));
}

bool getCachedData(CacheEntry* entry, unsigned long ttl) {
  if (!entry->valid) return false;
  if (millis() - entry->timestamp > ttl) {
    entry->valid = false;
    return false;
  }
  Serial.println(F("[Cache] HIT"));
  return true;
}

void cacheData(CacheEntry* entry, const String& data) {
  entry->data = data;
  entry->timestamp = millis();
  entry->valid = true;
  Serial.println(F("[Cache] Stored"));
}

// ------------------- F1 LOGO ----------------------
const uint8_t F1_Logo[] PROGMEM = {
  0x00,0x00,0x00,0x7f,0xff,0xff,0xff,0xff,0x8f,0xfe,0x00,0x00,0x07,0xff,0xff,0xff,
  0xff,0xff,0x1f,0xfc,0x00,0x00,0x1f,0xff,0xff,0xff,0xff,0xfe,0x3f,0xf8,0x00,0x00,
  0x3f,0xff,0xff,0xff,0xff,0xfc,0x7f,0xf0,0x00,0x00,0x7f,0xff,0xff,0xff,0xff,0xf8,
  0xff,0xe0,0x00,0x01,0xff,0xff,0xff,0xff,0xff,0xf1,0xff,0xc0,0x00,0x03,0xff,0xff,
  0xff,0xff,0xff,0xe3,0xff,0x80,0x00,0x07,0xff,0xe0,0x00,0x00,0x00,0x07,0xff,0x00,
  0x00,0x0f,0xff,0x00,0x00,0x00,0x00,0x0f,0xfe,0x00,0x00,0x1f,0xfc,0x3f,0xff,0xff,
  0xff,0x1f,0xfc,0x00,0x00,0x3f,0xf8,0xff,0xff,0xff,0xfe,0x3f,0xf8,0x00,0x00,0x7f,
  0xf1,0xff,0xff,0xff,0xfc,0x7f,0xf0,0x00,0x00,0xff,0xe3,0xff,0xff,0xff,0xf8,0xff,
  0xe0,0x00,0x01,0xff,0xc7,0xff,0xff,0xff,0xf1,0xff,0xc0,0x00,0x03,0xff,0x8f,0xff,
  0xff,0xff,0xe3,0xff,0x80,0x00,0x07,0xff,0x3f,0xf8,0x00,0x00,0x07,0xff,0x00,0x00,
  0x0f,0xfe,0x7f,0xe0,0x00,0x00,0x0f,0xfe,0x00,0x00,0x1f,0xfc,0xff,0xc0,0x00,0x00,
  0x1f,0xfc,0x00,0x00,0x3f,0xf9,0xff,0x80,0x00,0x00,0x3f,0xf8,0x00,0x00,0x7f,0xf1,
  0xff,0x00,0x00,0x00,0x7f,0xf0,0x00,0x00
};

// ------------------- CALENDAR DATA ----------------------
unsigned lastRound = 0, nextRound = 0;
String lastDate, lastCircuit, lastLoc;
String nextDate, nextCircuit, nextLoc;
String lastGP, nextGP;
String nextTime, lastTime;

// ------------------- TIME ----------------------
#define MY_TZ "EST5EDT,M3.2.0/2,M11.1.0/2"
#define NTP1 "pool.ntp.org"
#define NTP2 "time.nist.gov"

struct tm timeinfo;

// ------------------- DEBUG TIME HELPERS ----------------------
// Get simulated time for logic/scheduling (uses offset in debug mode)
time_t getSimulatedTime() {
  #if DEBUG_MODE
    return time(nullptr) + debugTimeOffsetSeconds;
  #else
    return time(nullptr);
  #endif
}

// Get simulated local time and populate timeinfo struct
// In debug mode, this uses simulated time; otherwise uses real time
bool getSimulatedLocalTime(struct tm* timeinfo) {
  #if DEBUG_MODE
    time_t simTime = getSimulatedTime();
    return localtime_r(&simTime, timeinfo) != nullptr;
  #else
    return getLocalTime(timeinfo);
  #endif
}

// ------------------- PERSISTED STATE ----------------------
Preferences prefs;
unsigned processedRound = 0;
time_t   nextRaceEpoch   = 0;
String   nextRaceDateStr;

// ------------------- CACHED VALUES (optimization) ----------------------
time_t   cachedLastRaceEpoch = 0;  // Cached lastRaceEpoch calculation
time_t   cachedNowEpoch = 0;        // Cached current time (updated per cycle)
unsigned cachedLastRaceRound = 0;  // Track when lastRaceEpoch was calculated
unsigned cachedQualifyingRound = 0; // Track which round we checked qualifying for
bool     cachedQualifyingAvailable = false; // Cached qualifying availability


String buildApiUrl(const char* suffix) {
  struct tm currentTime;
  if (!getLocalTime(&currentTime)) {
    return ""; // fallback if time not available
  }
  int currentYear = 1900 + currentTime.tm_year;
  String seasonStr = String(currentYear);
  
  char baseUrl[80];
  snprintf_P(baseUrl, sizeof(baseUrl), API_BASE_TEMPLATE, seasonStr.c_str());
  
  return String(baseUrl) + String(FPSTR(suffix));
}

// Build the season base URL, independent of global timeinfo
// NOTE: Always uses REAL time (not simulated) so API calls fetch correct year's data
String seasonBaseUrl() {
  time_t now = time(nullptr);  // Real time for API calls
  struct tm ti = {};
  localtime_r(&now, &ti);
  int currentYear = ti.tm_year + 1900;

  char baseUrl[96];
  snprintf_P(baseUrl, sizeof(baseUrl), API_BASE_TEMPLATE, String(currentYear).c_str());
  return String(baseUrl);
}

// ------------------- WIFI CONNECTION -------------------
bool setup_wifi() {
  WiFiManager wm;
  wm.setConfigPortalTimeout(300); // 5 minute timeout
  
  Serial.println(F("Attempting to connect to WiFi..."));
  
  if (wm.autoConnect("F1Tracker-Setup", "formula1")) { 
    Serial.println(F("WiFi connected successfully!"));
    Serial.println("IP: " + WiFi.localIP().toString());
    wifiConnected = true;
    configTime(0, 0, NTP1, NTP2);
    setenv("TZ", MY_TZ, 1);
    tzset();
    return true;
  }
  
  Serial.println(F("Failed to connect to WiFi."));
  wifiConnected = false;
  return false;
}

// ------------------- HELPERS -------------------

// Safer UTF-8: skip stray continuation bytes & cut by codepoints
String utf8_substr(const String& s, int codepoints) {
  if (s.length() == 0 || codepoints <= 0) return "";
  
  const char* p = s.c_str();
  if (!p) return "";
  
  String out;
  out.reserve(codepoints * 4);  // Reserve space for worst-case UTF-8 (4 bytes per char)
  int seen = 0;
  
  while (*p && seen < codepoints) {
    uint8_t c = (uint8_t)*p;
    if ((c & 0xC0) == 0x80) { p++; continue; }
    int bytes = 1;
    if ((c & 0xF8) == 0xF0) bytes = 4;
    else if ((c & 0xF0) == 0xE0) bytes = 3;
    else if ((c & 0xE0) == 0xC0) bytes = 2;
    for (int i = 0; i < bytes && *p; i++) out += *p++;
    seen++;
  }
  return out;
}

static const int LINE_H = 12;

void clearLineArea(int x, int y, int h = LINE_H) {
  display.fillRect(x, y, SCREEN_WIDTH - x, h, GxEPD_WHITE);
}

int textWidth(const char* s) {
  return gfx.getUTF8Width(s);
}

// Forward declarations
bool qualifyingAvailableForRound(unsigned round);
bool resultsAvailableForLastRound();
void DrawStartingGrid(unsigned round);
void DrawDriversStandings();
void ensureWiFiConnected();
void disconnectWiFiIfIdle();

// Local date as MM/DD
String nextRaceLocalDateMMDD() {
  time_t epoch = nextRaceEpoch ? nextRaceEpoch : isoUtcToEpoch(nextDate, nextTime);
  if (!epoch) return "";
  struct tm loc = {};
  if (!localtime_r(&epoch, &loc)) return "";
  char buf[16];
  if (strftime(buf, sizeof(buf), "%m/%d", &loc) == 0) return "";
  return String(buf);
}

String nextRaceLocalTimeLower() {
    if (nextRound == 0 || nextRaceEpoch == 0) return "";

    struct tm loc = {};
    if (!localtime_r(&nextRaceEpoch, &loc)) {
        return "";
    }

    char temp_buf[32];
    if (strftime(temp_buf, sizeof(temp_buf), "%I:%M %p", &loc) == 0) {
        return "";
    }

    char* src = temp_buf;
    if (temp_buf[0] == '0') {
        src++; 
    }

    String result;
    result.reserve(16);  // Pre-allocate to reduce fragmentation
    
    while (*src != '\0' && result.length() < 15) {
        char c = tolower(*src);
        
        if (isdigit(c) || c == ':' || c == 'a' || c == 'p' || c == 'm' || c == ' ') {
            result += c;
        }
        src++;
    }
    
    result.trim();  // Remove trailing spaces
    
    return result;
}

static time_t timegm_utc(struct tm* tm) {
  int year  = tm->tm_year + 1900;
  int month = tm->tm_mon + 1;
  if (month <= 2) { year -= 1; month += 12; }
  int64_t days = 365LL * year + year/4 - year/100 + year/400
               + (153*(month-3) + 2)/5 + tm->tm_mday - 719469;
  return days * 86400 + tm->tm_hour * 3600 + tm->tm_min * 60 + tm->tm_sec;
}

String cleanTime(String t) {
  int z = t.indexOf('Z'); if (z >= 0) t.remove(z);
  if (t.length() == 0) t = F("00:00:00");
  return t;
}

time_t isoUtcToEpoch(const String& ymd, const String& hms) {
  if (ymd.length() == 0 || hms.length() == 0) return 0;
  
  int y, m, d, hh = 0, mm = 0, ss = 0;
  if (sscanf(ymd.c_str(), "%4d-%2d-%2d", &y, &m, &d) != 3) return 0;
  sscanf(hms.c_str(), "%2d:%2d:%2d", &hh, &mm, &ss);
  
  // Validate date/time ranges
  if (y < 2000 || y > 2100 || m < 1 || m > 12 || d < 1 || d > 31) return 0;
  if (hh < 0 || hh > 23 || mm < 0 || mm > 59 || ss < 0 || ss > 59) return 0;
  
  struct tm t = {};
  t.tm_year = y - 1900; t.tm_mon = m - 1; t.tm_mday = d;
  t.tm_hour = hh; t.tm_min = mm; t.tm_sec = ss; t.tm_isdst = 0;
  return timegm_utc(&t);
}

// ------------------- RACE STATE DETECTION -------------------
bool isRaceInProgress() {
  if (nextRaceEpoch == 0) return false;
  
  time_t now = getSimulatedTime();  // Use simulated time for logic
  long diffToRaceStart = nextRaceEpoch - now;
  
  // Race is "in progress" from start time until +4 hours
  // OR if we're past race start but API hasn't updated yet (lastRound hasn't incremented)
  if (diffToRaceStart <= 0 && diffToRaceStart >= -RACE_IN_PROGRESS_WINDOW_SEC) {
    return true;
  }
  
  return false;
}

bool isInRaceWindow() {
  // Race window = 6 hours before race start to 6 hours after
  if (nextRaceEpoch == 0) return false;
  
  time_t now = getSimulatedTime();  // Use simulated time for logic
  long diff = nextRaceEpoch - now;
  
  return (diff <= RACE_WINDOW_BEFORE_SEC && diff >= -RACE_WINDOW_AFTER_SEC);
}

// ------------------- HTTP ----------------------
template <typename TFilterDoc>
bool httpDeserializeFromBuffer(const String& payload,
                               StaticJsonDocument<API_SCRATCH_DOC_SIZE>& target,
                               TFilterDoc* filter) {
  if (payload.length() == 0) {
    Serial.println(F("[ERR] HTTP body empty"));
    return false;
  }

  DeserializationError err;
  if (filter) {
    err = deserializeJson(target, payload, DeserializationOption::Filter(*filter));
  } else {
    err = deserializeJson(target, payload);
  }

  if (err) {
    Serial.printf("[ERR] JSON parse failed: %s (body %u bytes, heap %u)\n",
                  err.c_str(), payload.length(), ESP.getFreeHeap());
    return false;
  }
  return true;
}

template <typename TFilterDoc>
bool httpGetJsonRaw(const char* url, TFilterDoc* filter = nullptr) {
  // Ensure WiFi is connected before making API call
  ensureWiFiConnected();

  doc.clear();

  Serial.printf("\n--- HTTP Request ---\nAPI: %s\n", url);

  HTTPClient http;
  http.begin(url);
  http.setConnectTimeout(20000);
  http.setTimeout(45000);
  http.addHeader("User-Agent", "F1Tracker/NanoESP32");
  http.addHeader("Accept-Encoding", "identity");

  int httpCode = http.GET();
  Serial.printf("HTTP Status Code: %d\n", httpCode);
  if (httpCode != HTTP_CODE_OK) {
    Serial.printf("[ERR] HTTP GET failed. Code %d\n", httpCode);
    http.end();
    return false;
  }

  int expectedSize = http.getSize();
  Serial.println(F("[STEP] net: Reading body"));
  String payload;
  if (expectedSize > 0) payload.reserve((size_t)expectedSize + 1);
  payload = http.getString();
  http.end();

  Serial.printf("[INFO] Received %u bytes", payload.length());
  if (expectedSize > 0) Serial.printf(" (expected %d)", expectedSize);
  Serial.println();

  if (expectedSize > 0 && (int)payload.length() < expectedSize) {
    Serial.printf("[ERR] Incomplete HTTP body (%u/%d bytes, heap %u)\n",
                  payload.length(), expectedSize, ESP.getFreeHeap());
    return false;
  }

  Serial.println(F("[STEP] net: Deserializing"));
  bool ok = httpDeserializeFromBuffer(payload, doc, filter);
  if (!ok) return false;

  Serial.println(F("[INFO] JSON success."));
  return true;
}

template <typename TFilterDoc>
bool httpGetJsonWithRetry(const char* url,
                          int tries = 3,
                          int backoff_ms = 500,
                          TFilterDoc* filter = nullptr) {
  for (int i = 0; i < tries; i++) {
    if (httpGetJsonRaw(url, filter)) return true;
    delay(backoff_ms);
    backoff_ms *= 2;
  }
  return false;
}

// ------------------- CACHED API FUNCTIONS ----------------------
template <typename TFilterDoc>
bool fetchCalendarWithCache(TFilterDoc* filter = nullptr) {
  String url = buildApiUrl(API_RACES_SUFFIX);
  
  // Check cache first
  if (getCachedData(&apiCache.calendar, CACHE_TTL_CALENDAR)) {
    DeserializationError err;
    if (filter) {
      err = deserializeJson(doc, apiCache.calendar.data, DeserializationOption::Filter(*filter));
    } else {
      err = deserializeJson(doc, apiCache.calendar.data);
    }
    if (!err) return true;
    // If deserialization failed, fall through to fetch fresh
  }
  
  // Fetch fresh data
  Serial.print(F("[Cache] MISS - Fetching: "));
  if (!httpGetJsonWithRetry(url.c_str(), 3, 500, filter)) return false;
  
  // Cache the raw JSON for next time
  String jsonStr;
  serializeJson(doc, jsonStr);
  cacheData(&apiCache.calendar, jsonStr);
  
  return true;
}
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
void loop() {
  // Get current time (doesn't require WiFi) - uses simulated time in debug mode
  if (!getSimulatedLocalTime(&timeinfo)) {
    // Time sync failed - reconnect WiFi and retry
    ensureWiFiConnected();
    if (!getSimulatedLocalTime(&timeinfo)) {
      delay(1000);
      return;
    }
  }
  
  int currentMinute = timeinfo.tm_min;
  
  // Check if it's time to update (skip auto-updates in debug mode if disabled)
  #if DEBUG_MODE
    bool shouldAutoUpdate = debugAutoRefresh && shouldUpdateNow(currentMinute);
  #else
    bool shouldAutoUpdate = shouldUpdateNow(currentMinute);
  #endif
  
  if (shouldAutoUpdate) {
    lastCheckMinute = currentMinute;
    
    Serial.printf("\n[Scheduler] Wall-clock aligned update at %02d:%02d\n", 
                  timeinfo.tm_hour, timeinfo.tm_min);

    // Ensure WiFi is connected for API calls
    ensureWiFiConnected();

    // Re-read calendar to detect round changes / next race timing shifts
    FetchCalendar();

    // Decide if we need to invalidate standings cache
    bool newRoundFinished = (processedRound != lastRound && lastRound != 0);
    bool haveResults      = resultsAvailableForLastRound();
    
    // Invalidate standings cache when race finishes
    if (newRoundFinished) {
      invalidateStandingsCache();
    }

    // Always do full refresh (simpler for e-paper)
    fullRefreshAndReschedule();
    
    // Disconnect WiFi after update to save power
    disconnectWiFiIfIdle();
  }
  
  // Check every 60 seconds (updates only happen at minute boundaries)
  // In debug mode, check for commands every second for responsive interaction
  #if DEBUG_MODE
    // Check for commands every second in debug mode (60 checks = 60 seconds)
    for (int i = 0; i < 60; i++) {
      handleDebugCommands();  // Check for commands every second
      delay(1000);
    }
  #else
    delay(60000);
  #endif
}
